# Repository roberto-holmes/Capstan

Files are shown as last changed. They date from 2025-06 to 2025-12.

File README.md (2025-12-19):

# Specifications

## v1

- USB HID scroll wheel
- BT HID scroll wheel
- Battery Charging with protections:
  - Overvoltage
  - Undervoltage
  - Overcurrent
  - Over temp
  - Reverse battery protection
- Motor

## Future

- FFB
- High resolution scrolling
- Set battery charge level limits
- Load sharing/Power path
- Coulomb counting

- LSE for STM32?

## RF

- Is this antenna suitable?
- Do we need two pi filters?
- Are the pi filter values a good start point?
- Do we need test points for calibration?

# Review Notes 2025/08/11

- ~~move the motor current sense from low side to the switched line~~
- ~~current sensor is 680uA - too high for long term storage (ok?)~~
  - Low power is not priority at the moment
- ~~why 27 ohm gate resistors? suggest 6V/600mA = 10ohm~~
  - Max gate driver current is 250mA
- add decouple to +2V5
- ~~lower the Hall effect sensor data series resistor, suggest 100ohm~~
  - Setting R46 to be DNP instead
- ~~USB diode protection U2 is connected wrong~~
- ~~recommend use TPS61041 rather than TPS61040 (250mA peak rather than 400mA peak - we don't need that much)~~
- ~~C18 is far too high ( I think 33pF ok )~~
  - Using 10pF as recommended by datasheet

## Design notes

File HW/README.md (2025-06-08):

MCU:
STM32WB55CG

- 'C' variant is the smallest, will ikely not need the additional pins of the 'R' or 'V' variants
- 'G' for maximum flash (1MB)

Using [Raspberry Pi Debug Connector Spec](https://datasheets.raspberrypi.com/debug/debug-connector-specification.pdf)

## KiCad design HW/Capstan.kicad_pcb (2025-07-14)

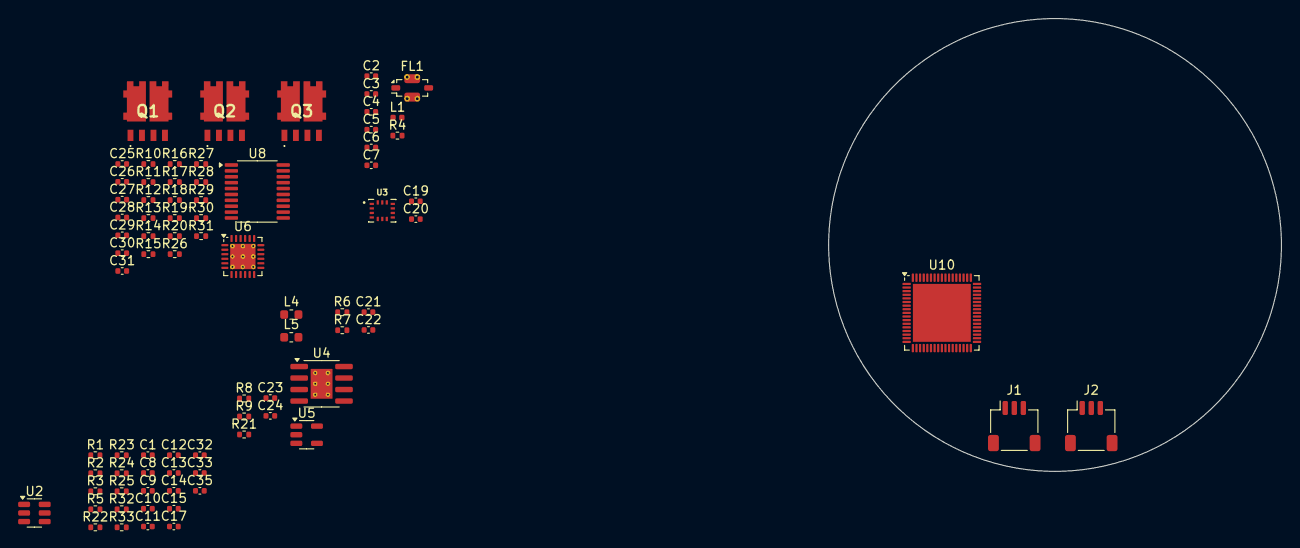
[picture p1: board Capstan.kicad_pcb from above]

Board: 2 copper layers, 50.0 x 50.0 mm, 81 parts (0 on the bottom side), 57 nets, no tracks yet.

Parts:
C1, C8, C9, C10, C11, C12, C13, C14, C19, C20, C25, C26, C27, C28, C33, C35: 100nF; C_0402_1005Metric
C2: 0.8pF; C_0402_1005Metric
C3: 0.3pF; C_0402_1005Metric
C4: 0.4pF; C_0402_1005Metric
C5: 0.2pF; C_0402_1005Metric
C6, C7: C_0402_1005Metric
C15: 100pF; C_0402_1005Metric
C17, C32: 4.7uF; C_0402_1005Metric
C21, C22: 10uF; C_0402_1005Metric
C23, C24: 1uF; C_0402_1005Metric
C29: CREG12; C_0402_1005Metric
C30, C31: 1nF; C_0402_1005Metric
FL1: BFCN-2450; Filter_Mini-Circuits_FV1206-4
J1: SWD; JST_SH_SM03B-SRSS-TB_1x03-1MP_P1.00mm_Horizontal
J2: UART; JST_SH_SM03B-SRSS-TB_1x03-1MP_P1.00mm_Horizontal
L1: 2.7nH; L_0402_1005Metric
L4: 10uH; L_0603_1608Metric
L5: FCM1608KF-601T03; L_0603_1608Metric
Q1, Q2, Q3: STL40DN3LLH5
R1, R25: 18kΩ; R_0402_1005Metric
R2, R22: 24kΩ; R_0402_1005Metric
R3: 56kΩ; R_0402_1005Metric
R4: 0Ω; R_0402_1005Metric
R5, R11, R18, R20: 10kΩ; R_0402_1005Metric
R6: 2.2kΩ; R_0402_1005Metric
R7, R8: 1kΩ; R_0402_1005Metric
R9: 0.4Ω; R_0402_1005Metric
R10, R17, R26, R27, R29, R30: 27Ω; R_0402_1005Metric
R12, R13, R14, R15: kΩ; R_0402_1005Metric
R16: 39kΩ; R_0402_1005Metric
R19, R28, R31: 12.5mΩ; R_0402_1005Metric
R21: 125mΩ; R_0402_1005Metric
R23, R24, R32, R33: 100Ω; R_0402_1005Metric
U2: USBLC6-2SC6; SOT-23-6
U3: BMI270; XDCR_BMI270
U4: TP4056-42-ESOP8; SOIC-8-1EP_3.9x4.9mm_P1.27mm_EP2.41x3.3mm_ThermalVias
U5: AP2112K-3.3; SOT-23-5
U6: STDRIVE101; QFN-24-1EP_4x4mm_P0.5mm_EP2.8x2.8mm_ThermalVias
U8: INA4181A1; TSSOP-20_4.4x6.5mm_P0.65mm
U10: STM32WB55RGVx; QFN-68-1EP_8x8mm_P0.4mm_EP6.4x6.4mm

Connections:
+2V5: R2.2, U8.20 (REF), U10.13 (VREF+)
+3V3: C9.1, C10.1, C11.1, C12.1, C13.1, C14.1, C15.1, C17.1, C19.1, C20.1, C24.1, C31.1, C33.2, L5.1, R11.2, R12.2, R16.2, U3.5 (VDDIO), U3.8 (VDD), U5.5 (VOUT), U8.5 (VS), U10.1 (VBAT), U10.30 (VDD), U10.33 (VDDRF), U10.44 (VDDSMPS), U10.45 (VDD), U10.55 (VDDUSB), U10.68 (VDD)
+BATT: C8.1, Q1.6 (D), Q2.6 (D), Q3.6 (D), R21.2, R22.2, U8.18 (-)
/MCU/BOOT0: R5.2, U10.5 (PH3)
/MCU/MCU_D+: U2.1 (I/O1), U10.53 (PA12)
/MCU/MCU_D-: U2.3 (I/O2), U10.52 (PA11)
/MCU/SWDCLK: J1.1, R24.2
/MCU/SWDIO: J1.3, R23.2
/MCU/UART_RX: J2.1, R33.2
/MCU/UART_TX: J2.3, R32.2
/MCU/~RST: C1.1, U10.8 (NRST)
/Motor/A: C25.1, Q1.1 (S), Q1.5 (D), Q2.1 (S), Q2.5 (D), Q3.1 (S), Q3.5 (D), U6.23 (OUT1)
/Motor/GHS1: R17.1, R26.1, R29.1, U6.22 (GHS1)
/Motor/GLS1: R10.1, R27.1, R30.1, U6.24 (GLS1)
/Motor/SENSE_1: U8.2, U8.8, U8.13
/Motor/SHS2: C27.2, U6.19 (OUT2)
/Motor/SHS3: C26.2, U6.15 (OUT3)
/Motor/VREF: U8.1 (REF), U8.9 (REF), U8.12 (REF)
/Motor/~FAULT: R16.1, U6.6 (NFAULT)
/RF/RF: C2.1, L1.1
GND: C1.2, C2.2, C3.2, C5.2, C6.2, C7.2, C8.2, C9.2, C10.2, C11.2, C12.2, C13.2, C14.2, C15.2, C17.2, C19.2, C20.2, C22.2, C23.2, C24.2, C28.2, C29.2, C30.2, C31.2, C32.2, C33.1, C35.2, FL1.2 (GND), FL1.4 (GND), J1.2, J2.2, R1.1, R5.1, R6.1, R19.1, R20.1, R25.1, R28.1, R31.1, U2.2 (GND), U3.6 (GNDIO), U3.7 (GND), U4.3 (GND), U4.9 (EPAD), U5.2 (GND), U6.2 (DT/MODE), U6.25 (GND), U8.3 (-), U8.7 (-), U8.14 (-), U8.16 (GND), U10.32 (VSSRF), U10.42 (VSSSMPS), U10.69 (VSS)
unnamed: C5.1, C6.1, R4.2
unnamed: C22.1, U4.5 (BAT)
unnamed: C4.1, C7.1, R4.1
unnamed: C21.1, R9.1, U4.4 (V_{CC}), U4.8 (CE)
unnamed: C3.1, FL1.1 (IN), L1.2
unnamed: C4.2, FL1.3 (OUT)
unnamed: Q1.2 (G), R26.2
unnamed: Q1.4 (G), R27.2
unnamed: Q1.3 (S), R28.2, U8.6 (+)
unnamed: Q2.2 (G), R17.2
unnamed: Q2.4 (G), R10.2
unnamed: Q2.3 (S), R19.2, U8.4 (+)
unnamed: Q3.2 (G), R29.2
unnamed: Q3.4 (G), R30.2
unnamed: Q3.3 (S), R31.2, U8.15 (+)
unnamed: R6.2, U4.2 (PROG)
unnamed: R7.1, U4.7 (~CHRG)
unnamed: R8.1, U4.6 (~STDBY)
unnamed: C23.1, R21.1, U5.1 (VIN), U5.3 (EN), U8.17 (+)
unnamed: C25.2, U6.21 (BOOT1)
unnamed: C27.1, U6.17 (BOOT2)
unnamed: C26.1, U6.13 (BOOT3)
unnamed: C30.1, R12.1, R13.2, R14.2, R15.2, U6.1 (CP)
unnamed: R11.1, U6.3 (SCREF)
unnamed: R18.1, R20.2
unnamed: R22.1, R25.2, U10.15 (PA0)
unnamed: R1.2, R2.1, U10.16 (PA1)
unnamed: R32.1, U10.17 (PA2)
unnamed: R33.1, U10.18 (PA3)
unnamed: R23.1, U10.54 (PA13)
unnamed: R24.1, U10.56 (PA14)
unnamed: C35.1, L5.2, U10.14 (VDDA)
unnamed: C32.1, L4.2, U10.41 (VFBSMPS)
unnamed: L4.1, U10.43 (VLXSMPS)
VBUS: R3.2, R9.2, U2.5 (VBUS)
VS: C28.1, C29.1, U6.4 (VS), U6.5 (REG12)

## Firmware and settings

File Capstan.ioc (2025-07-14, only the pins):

Mcu.UserName=STM32WB55RGVx
PA0.GPIO_Label=BATT_SENSE
PA0.Signal=ADCx_IN5
PA1.GPIO_Label=MOTOR_TEMP
PA1.Signal=ADCx_IN6
PA10.Signal=S_TIM1_CH3
PA11.Signal=USB_DM
PA12.Signal=USB_DP
PA15.GPIO_Label=IMU_NSS
PA15.Signal=SPI1_NSS
PA2.GPIO_Label=DEBUG_TX
PA2.Signal=LPUART1_TX
PA3.GPIO_Label=DEBUG_RX
PA3.Signal=LPUART1_RX
PA7.Signal=TIM1_CH1N
PA8.Signal=S_TIM1_CH1
PA9.Signal=S_TIM1_CH2
PB0.GPIO_Label=BUTTON2
PB0.Signal=GPIO_Input
PB1.GPIO_Label=BUTTON1
PB1.Signal=GPIO_Input
PB10.GPIO_Label=LED_GREEN
PB10.Signal=GPIO_Output
PB11.GPIO_Label=LED_BLUE
PB11.Signal=GPIO_Output
PB12.Signal=SPI2_NSS
PB13.Signal=SPI2_SCK
PB14.Signal=SPI2_MISO
PB15.Signal=SPI2_MOSI
PB2.GPIO_Label=LED_RED
PB2.Signal=GPIO_Output
PB3.GPIO_Label=IMU_SCK
PB3.Signal=SPI1_SCK
PB4.GPIO_Label=IMU_MISO
PB4.Signal=SPI1_MISO
PB5.GPIO_Label=IMU_MOSI
PB5.Signal=SPI1_MOSI
PB6.GPIO_Label=IMU_INT1
PB6.Signal=GPXTI6
PB7.GPIO_Label=IMU_INT2
PB7.Signal=GPXTI7
PB8.Signal=TIM1_CH2N
PB9.Signal=TIM1_CH3N
PC0.GPIO_Label=CURRENT_SENSE_SYSTEM
PC0.Signal=ADCx_IN1
PC1.GPIO_Label=CURRENT_SENSE_MOTOR_1
PC1.Signal=ADCx_IN2
PC13.GPIO_Label=STDRIVE_nFAULT
PC13.Signal=GPXTI13
PC2.GPIO_Label=CURRENT_SENSE_MOTOR_2
PC2.Signal=ADCx_IN3
PC3.GPIO_Label=CURRENT_SENSE_MOTOR_3
PC3.Signal=ADCx_IN4

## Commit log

2025-06-08 Added a start at schematic design
    [Capstan.kicad_pcb, Capstan.kicad_sch, battery.kicad_sch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]
2025-07-14 Almost first schematic draft (missing resistor values for STDRIVE current sensing and leds)
    [Capstan.kicad_pcb, Capstan.kicad_sch, battery.kicad_sch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]
2025-07-26 Added resistor values for LED and removed STDRIVE current sensing
    [mcu.kicad_sch, motor.kicad_sch]
2025-09-21 Fixed USB ESD protection
    [mcu.kicad_sch]
2025-12-19 Cleaned up and implemented some of Laimonas' feedback
    [Capstan.kicad_sch, battery.kicad_sch, imu.kicad_sch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]
